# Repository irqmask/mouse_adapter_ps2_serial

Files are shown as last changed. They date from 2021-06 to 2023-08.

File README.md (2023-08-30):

# PS/2 to serial mouse adapter

This is an intelligent adapter to connect PS/2 mouses to serial mouses uses in the 80s and 90s.
Hope to help some retro-computer enthusiasts connecting a "more modern" mouse to theold PC.

Currently tested with 2-button ball mouses. Untested with optical mouses, yet.

I made this for fun, use this software and self-built hardware at your own risk (and with great fun)!

# Hardware

The hardware basically consists of a ATtiny2313 microcontroller and a MAX232 level shifter. The PS/2 is connected to the INT0 and INT1 pins of the ATtiny2313. The internal pull-up resistors are used for the idle state. 

The serial mouse is connected via a MAX232 to the UART of the ATtiny2313.
The schematics will give more details.

Schematic

This is the first prototype.

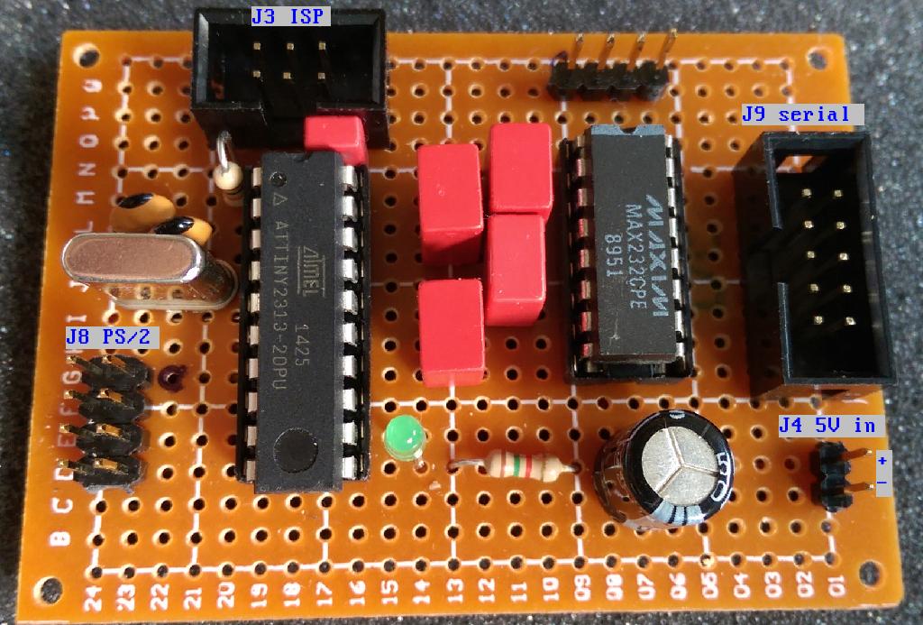
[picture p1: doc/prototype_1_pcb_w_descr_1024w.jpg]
This is the first prototype


The PS/2 connection is matching the connector of the PS/2 connector bracket which I found in an assortment of old computer cables.

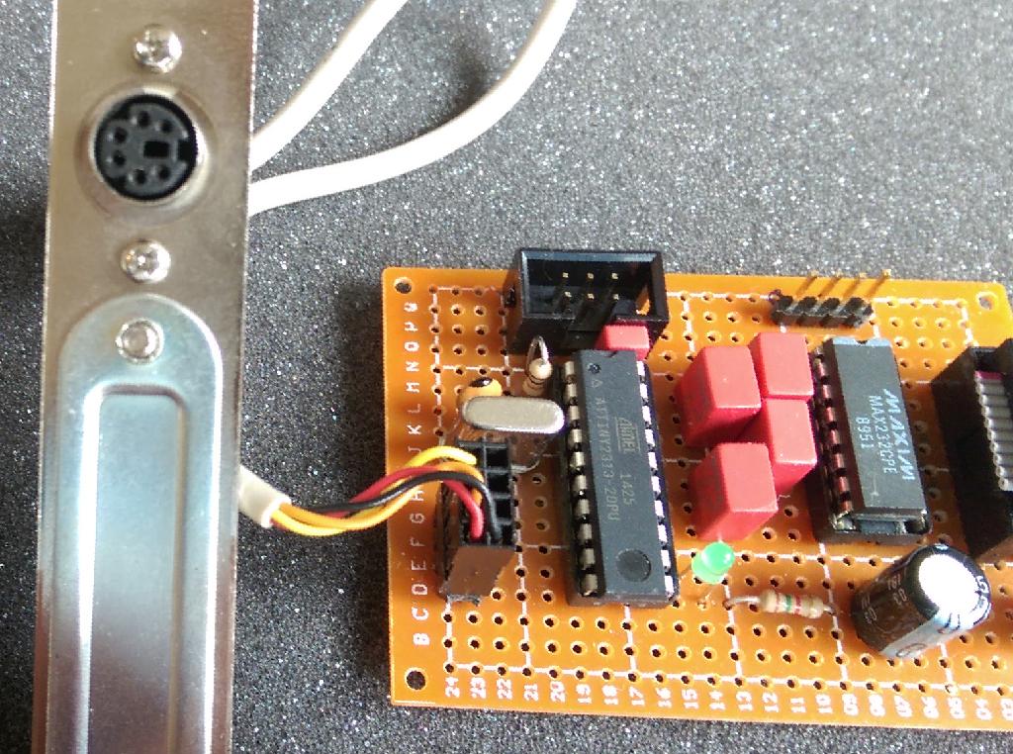
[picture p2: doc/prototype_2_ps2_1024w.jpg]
PS/2 connection


The RS232 connection for the mouse is a 1:1 connection between the Pin-header and the DB9 connector.
This allows to mount it inside an old PC and connect it directly to the interface card. 

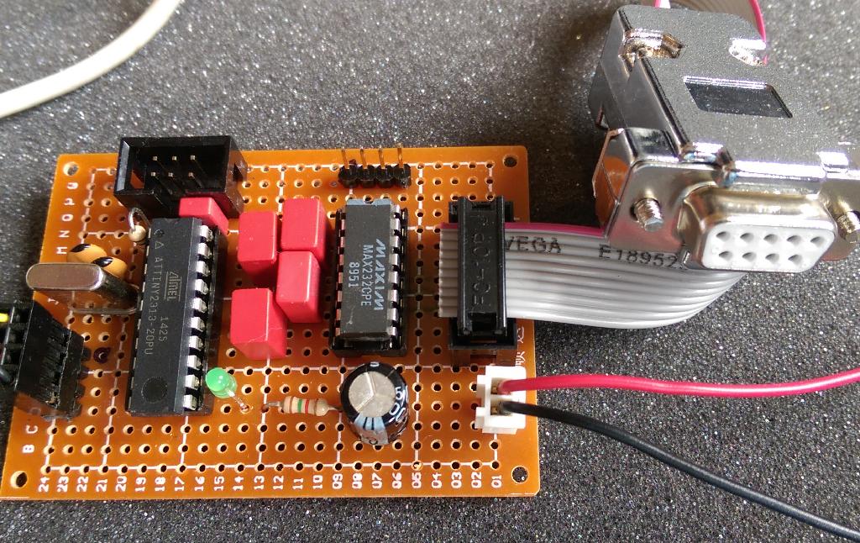
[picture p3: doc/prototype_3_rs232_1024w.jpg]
RS232 connection


Do not use the type of DB9 connectors which are crimped directly onto the cable! 

# Software


## How to build and program

First the assembler source code must be assembled into a hex file, then it can
be programmed to the microcontroller.

For assembling I use avr-gcc and avrdude under Ubuntu Linux

To install the assembler, simply execute

    sudo apt install gcc-avr avr-libc avrdude
    
To assemble the microcontroller software execute:

    cd sw/
    make
    
To program the device, avrdude is used with the AVR ISP mk2 programmer.
The fuses of the controller need to be programmed:

    avrdude -c avrispmkII -p t2313 -U lfuse:w:0xEE:m -U hfuse:w:0xDF:m -U efuse:w:0xFF:m

The assembled hex file is programmed like this:

    avrdude -c avrispmkII -p t2313 -e -U flash:w:mouse.hex -U flash:v:mouse.hex

or simply

    make program

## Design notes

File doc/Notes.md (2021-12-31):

# Design descisions

Why I've chosen GNU Assembler over AVRA?

* GNU Assembler supports generating object files from source files and link later.
* AVRA only supports '.include' directive, which can become cumbersome when more than one file use the same source file
https://www.avrfreaks.net/forum/multiple-source-files

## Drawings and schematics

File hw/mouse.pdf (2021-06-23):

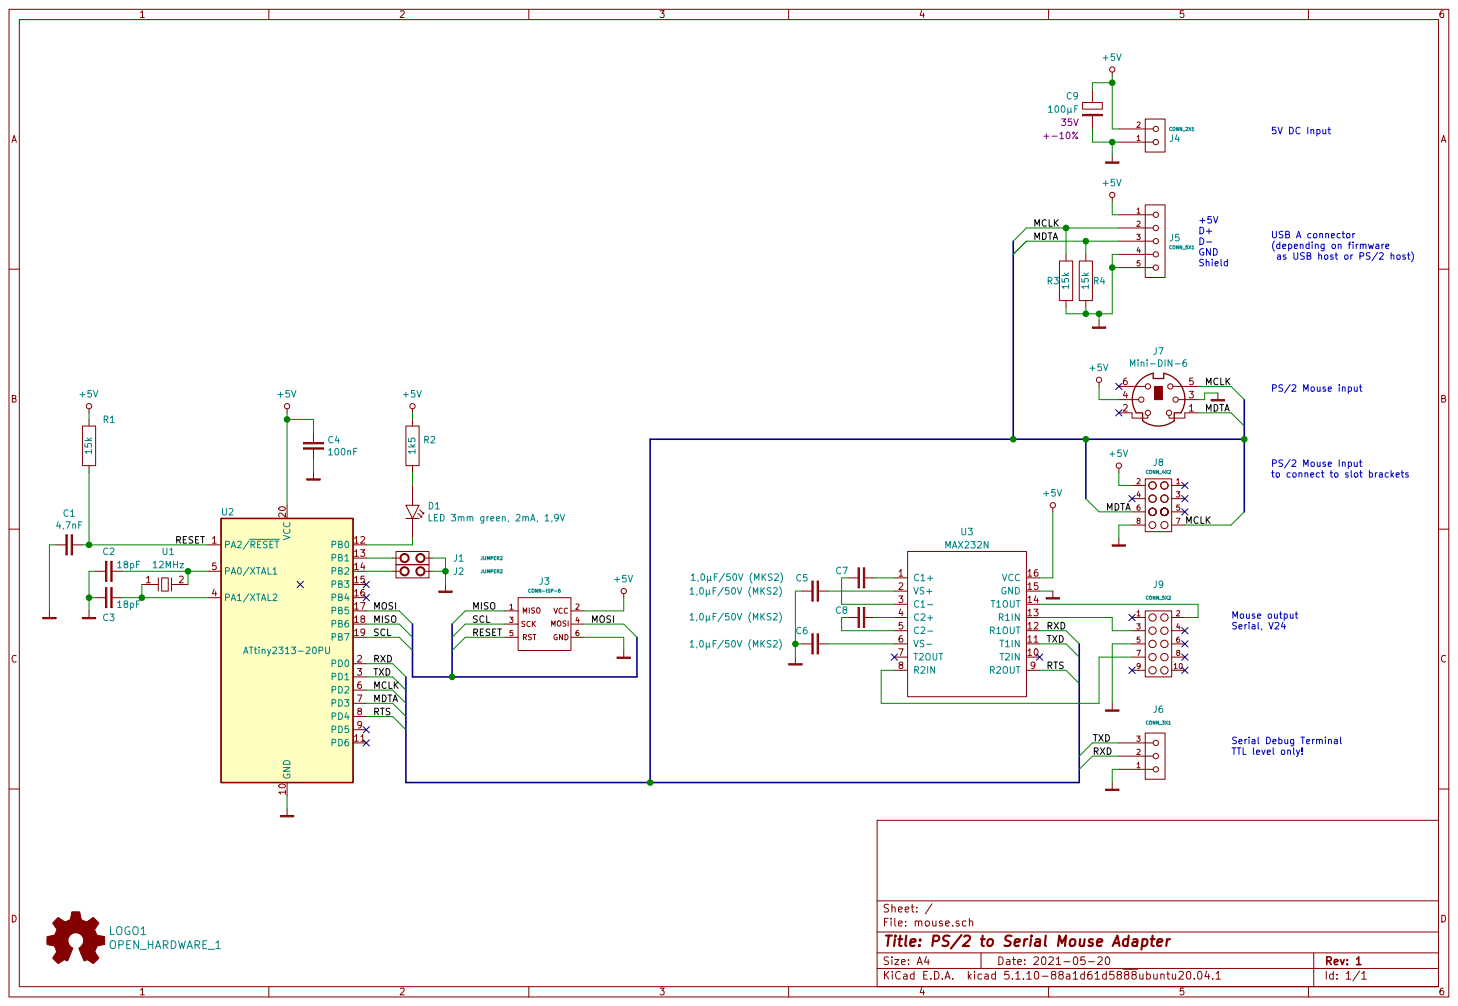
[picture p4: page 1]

to connect to slot brackets +5V D+D- GND

(depending on firmware
as USB host or PS/2 host)

Mouse output Serial, V24 Serial Debug Terminal

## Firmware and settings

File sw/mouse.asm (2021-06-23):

;
; PS/2 to serial mouse adapter
;
; Adapter to connect a PS/2 mouse to a PC with only a serial port.
;
; Copyright (C) 2021  christian <irqmask@web.de>
;
; This program is free software: you can redistribute it and/or modify
; it under the terms of the GNU General Public License as published by
; the Free Software Foundation, either version 3 of the License, or
; (at your option) any later version.
;
; This program is distributed in the hope that it will be useful,
; but WITHOUT ANY WARRANTY; without even the implied warranty of
; MERCHANTABILITY or FITNESS FOR A PARTICULAR PURPOSE.  See the
; GNU General Public License for more details.
;
; You should have received a copy of the GNU General Public License
; along with this program.  If not, see <http://www.gnu.org/licenses/>.
;

.include "tn2313def.inc"

; constants

.equ F_CPU = 12000000                           ; CPU clock in Hz
.equ F_CPU_KHZ = F_CPU / 1000                   ; CPU clock in kHz
; .equ BAUD  = 19200                          ; serial Baudrate of UART
.equ BAUD  = 1200                               ; serial Baudrate of UART

.equ PS2_BUFFER_SIZE = 3
.equ SERIAL_BUFFER_SIZE = 3

; calculations

.equ UBRR_VAL   = ((F_CPU+BAUD*8)/(BAUD*16)-1)  ; calc and round UBRR value
.equ BAUD_REAL  = (F_CPU/(16*(UBRR_VAL+1)))     ; real baudrate
.equ BAUD_ERROR = ((BAUD_REAL*1000)/BAUD-1000)  ; baudrate error error


.equ PS2_CMD_RESET = 0xFF
.equ PS2_CMD_SET_DEFAULTS = 0xF6
.equ PS2_CMD_EN_DATA_REPORTING = 0xF4
.equ PS2_CMD_SET_REMOTE_MODE = 0xF0
.equ PS2_CMD_SET_STREAM_MODE = 0xEA
.equ PS2_ACK = 0xFA

.if ((BAUD_ERROR>10) || (BAUD_ERROR<-10))       ; max. +/-1% deviation
  .error "Baudrate error > 1%"
.endif


.def value          = r17

.def ps2_bit_cnt    = r18
.def ps2_recv_val   = r19
.def ps2_byte_cnt   = r20
.def ps2_recv_ready = r21
.def ms_x           = r22
.def ms_y           = r23

.equ PS2_DDR        = DDRD
.equ PS2_PORT       = PORTD
.equ PS2_PIN        = PIND

.equ PS2_CLK_BIT    = 2
.equ PS2_DTA_BIT    = 3

.equ SER_PIN        = PIND
.equ SER_RTS_BIT    = 4

;------------------------------------------------------------------------------
; interrupt vector table
;------------------------------------------------------------------------------

.org 0x0000
    rjmp    reset
.org 0x0001                   ; External Interrupt0
    rjmp    ps2_irq_clk                   
.org 0x0002                   ; External Interrupt1
    reti                   
.org 0x0003                   ; Timer1 Capture
    reti                   
.org 0x0004                   ; Timer1 CompareA
    reti                   
.org 0x0005                   ; Timer1 Overflow
    reti                   
.org 0x0006                   ; Timer0 Overflow
    reti                   
.org 0x0007                   ; USART0 RX complete
    reti                   
.org 0x0008                   ; USART0 UDR empty 
    reti                   
.org 0x0009                   ; USART0 TX complete
    reti                   
.org 0x000A                   ; Analog comparator
    reti                   
.org 0x000B                   ; Pin change
    reti                   
.org 0x000C                   ; Timer1 CompareB
    reti                   
.org 0x000D                   ; Timer0 CompareA
    rjmp    ps2_timeout_irq
.org 0x000E                   ; Timer0 CompareB
    reti                   
.org 0x000F                   ; USI start
    reti                   
.org 0x0010                   ; USI overflow
    reti                   
.org 0x0011                   ; EEProm ready
    reti                   
.org 0x0012                   ; Watchdog overflow
    reti                   


;------------------------------------------------------------------------------
; main entry point
;------------------------------------------------------------------------------

.org INT_VECTORS_SIZE
reset:


main:
    ; initialize stack pointer

    ldi     r16, LOW(RAMEND)
    out     SPL, r16
    
    ; initialize ports
    ldi     r16, 0b00000001
    out     DDRB, r16
    ldi     r16, 0b00000000
    out     PORTB, r16
   
  
    ldi     r16, 0b00000000
    out     DDRD, r16
    ldi     r16, 0b00000000
    out     PORTD, r16
    
    rcall   serial_init
    rcall   ps2_init
    
    sei
    
loop:
    sbi     PORTB, 0    ; LED off
wait_rts_lo:
    sbis    SER_PIN, SER_RTS_BIT
    rjmp    send_ident
    rjmp    wait_rts_lo
      
send_ident:
    cbi     PORTB, 0    ; LED on
    rcall   delay14ms
    ldi     value, 'M'
    rcall   serial_send
    rcall   delay16ms
 
mouse_loop:
    tst     ps2_recv_ready
    breq    mouse_loop_end
    brmi    mouse_error
    
    cpi     ps2_recv_ready, 1
    breq    mouse_data
       
    rjmp    mouse_loop_end      ; no PS/2 data received
    
mouse_data:
    cli
    rcall   ps2_interrupt_disable
    rcall   ps2_recv_disable
    
    ; convert PS/2 mouse data into serial mouse data (Microsoft mouse protocol)
    ; the PS/2 mouse data packet has this format
    ;         Bit 7 | Bit 6 | Bit 5 | Bit 4 | Bit 3 | Bit 2 | Bit 1 | Bit 0
    ; Byte 0  Y ovl | X ovl | Y sgn | X sgn |   1   | M-Btn | R-Btn | L-Btn
    ; Byte 1                           X Movement
    ; Byte 2                           Y Movement

    ldi     r30, LOW(ps2_in_data)
    ldi     r31, HIGH(ps2_in_data)

    ;rjmp    mouse_debug_out
    
    ldi     value, 0b01000000

    ld      r16, Z              ; fetch PS/2 byte 0
    sbrc    r16, 0              ; check left button
    ori     value, 0b00100000
    sbrc    r16, 1              ; check right button
    ori     value, 0b00010000

    ldd     ms_x, Z+1

    ldd     ms_y, Z+2
    neg     ms_y
    
    mov     r16, ms_x           ; fetch PS/2 byte 1 for upper bits
    lsr     r16                 ; --- --- --- --- --- --- dx7 dx6
    lsr     r16
    lsr     r16
    lsr     r16
    lsr     r16
    lsr     r16
    andi    r16, 0b00000011
    or      value, r16

    mov     r16, ms_y           ; fetch PS/2 byte 2 for upper bits
    lsr     r16                 ; --- --- --- --- dy7 dy6 --- ---
    lsr     r16
    lsr     r16
    lsr     r16
    andi    r16, 0b00001100
    or      value, r16
    rcall   serial_send
    rcall   delay100us

    mov     value, ms_x         ; fetch PS/2 byte 1 for lower 6 bits
    andi    value, 0b00111111
    rcall   serial_send
    rcall   delay100us

    mov     value, ms_y         ; fetch PS/2 byte 2 for lower 6 bits
    andi    value, 0b00111111
    rcall   serial_send
    rcall   delay100us
    
    ; serial Microsoft mouse protocol
    ;         Bit 7 | Bit 6 | Bit 5 | Bit 4 | Bit 3 | Bit 2 | Bit 1 | Bit 0
    ; Byte 0            1   |   lb  |   rb  |  dy7  |  dy6  |  dx7  |  dx6
    ; Byte 1            0   |  dx5  |  dx4  |  dx3  |  dx2  |  dx1  |  dx0
    ; Byte 2            0   |  dy5  |  dy4  |  dy3  |  dy2  |  dy1  |  dy0

    rcall   ps2_reset_recv      ; reset PS/2 receive buffer
    rcall   ps2_recv_enable
    rcall   ps2_interrupt_enable
    sei
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

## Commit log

2021-06-23 Initial version.
    [mouse.kicad_pcb, mouse.sch]
2021-06-23 Move hardware one folder up, add pictures for documentation
    [mouse.kicad_pcb, mouse.sch]
2021-12-31 Converted code to GNU assembler and added Makefile
2021-12-31 add PS/2 analyzer tool
    read host and device data from PS/2 port without disturbing transmissing and
    print it as ASCII text on the serial port at 57600bd.
2022-01-01 Provide minor fixes and code cleanup
    minor fixes:
    * output 0 and CR LF in the beginning
    * limit number of bytes stored to array length
    cleanup:
    * deactivated pull-up resistors, since the analyzer must not disturb the bus
    * changed fuses (activate browout detection, change startup)
    * removed unused code
    * cleanup spaces
2022-01-01 Bug fix and cleanup after merging to avrgcc as assembler
    Bugfix
    * fixed naming of interrupts
    * removed BAUD definition from Makefile
    Cleanup
    * move PS2 code into own source file
    * delete spaces at end of line
2022-01-01 Increase timeout between bytes
    old KVM switch inserts bigger break between bytes
